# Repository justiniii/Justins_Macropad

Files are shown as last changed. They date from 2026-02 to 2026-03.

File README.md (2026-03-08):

# Justins_Macropad

A 5-key macropad with RGB underglow and OLED display, built around the Seeed XIAO RP2040. Designed for general shortcuts and everyday productivity. Macropad was designed off a sketch of my fingers so its perfectly ergonomic :)

---

## Challenges

This is my first PCB I am planning to manufacture, I used fusion to create the layout using a dxf using a sketch on paper. The keys are positioned to the size and position of my hand. After multiple changes I was eventually happy with the result. Fusion360 was used for 3D modelling with no issues.

---

## Schematic

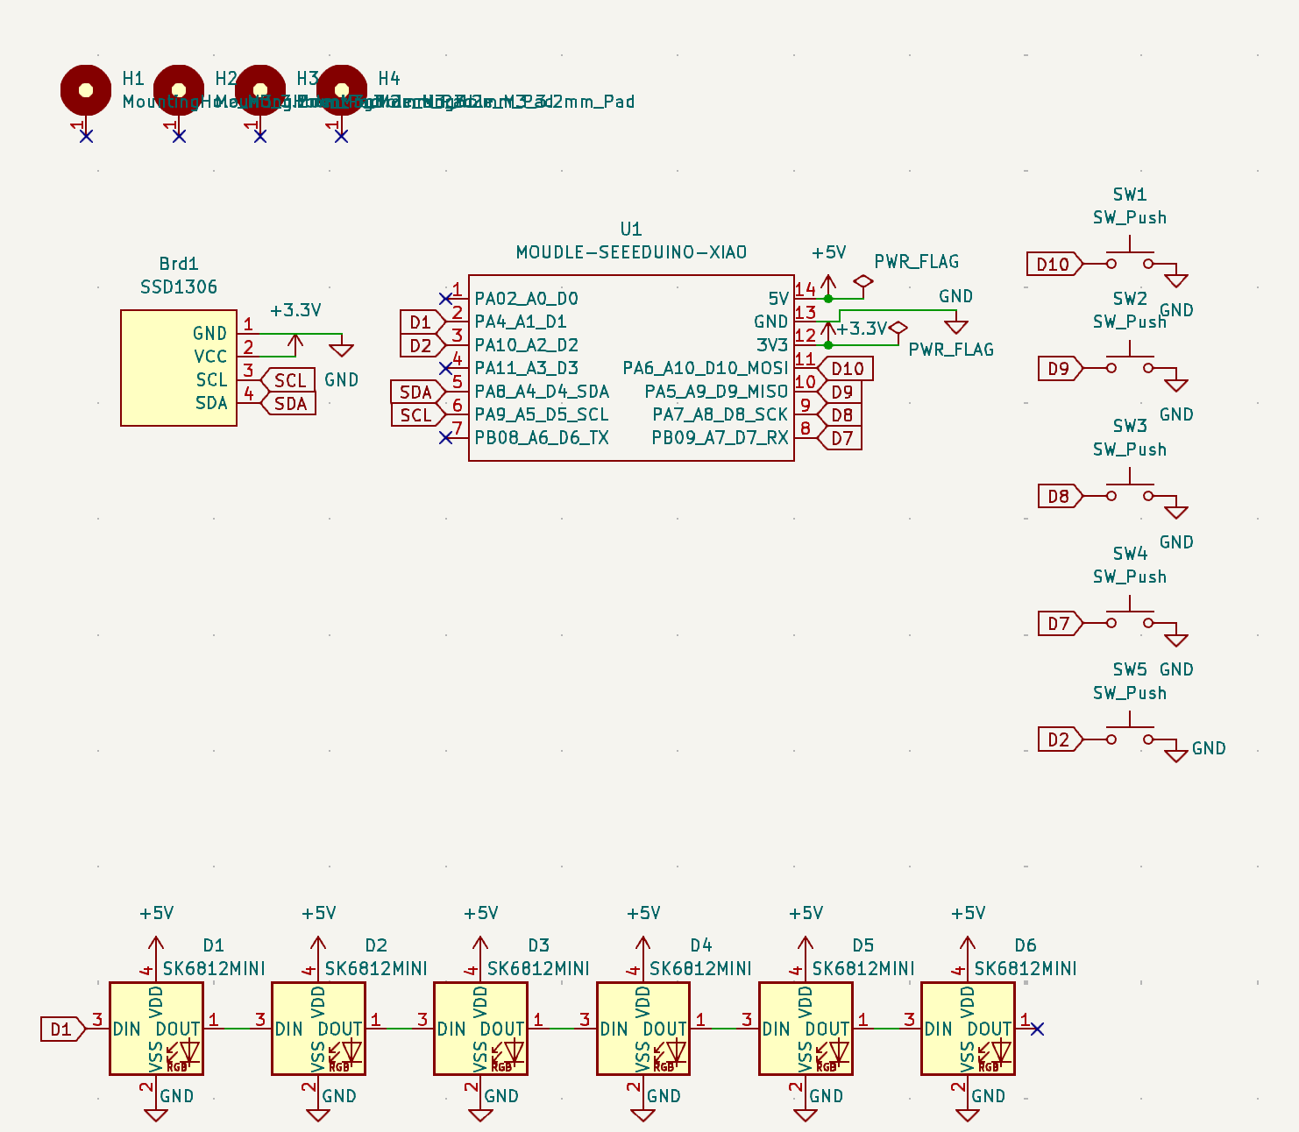
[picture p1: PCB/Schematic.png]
Schematic


---

## PCB

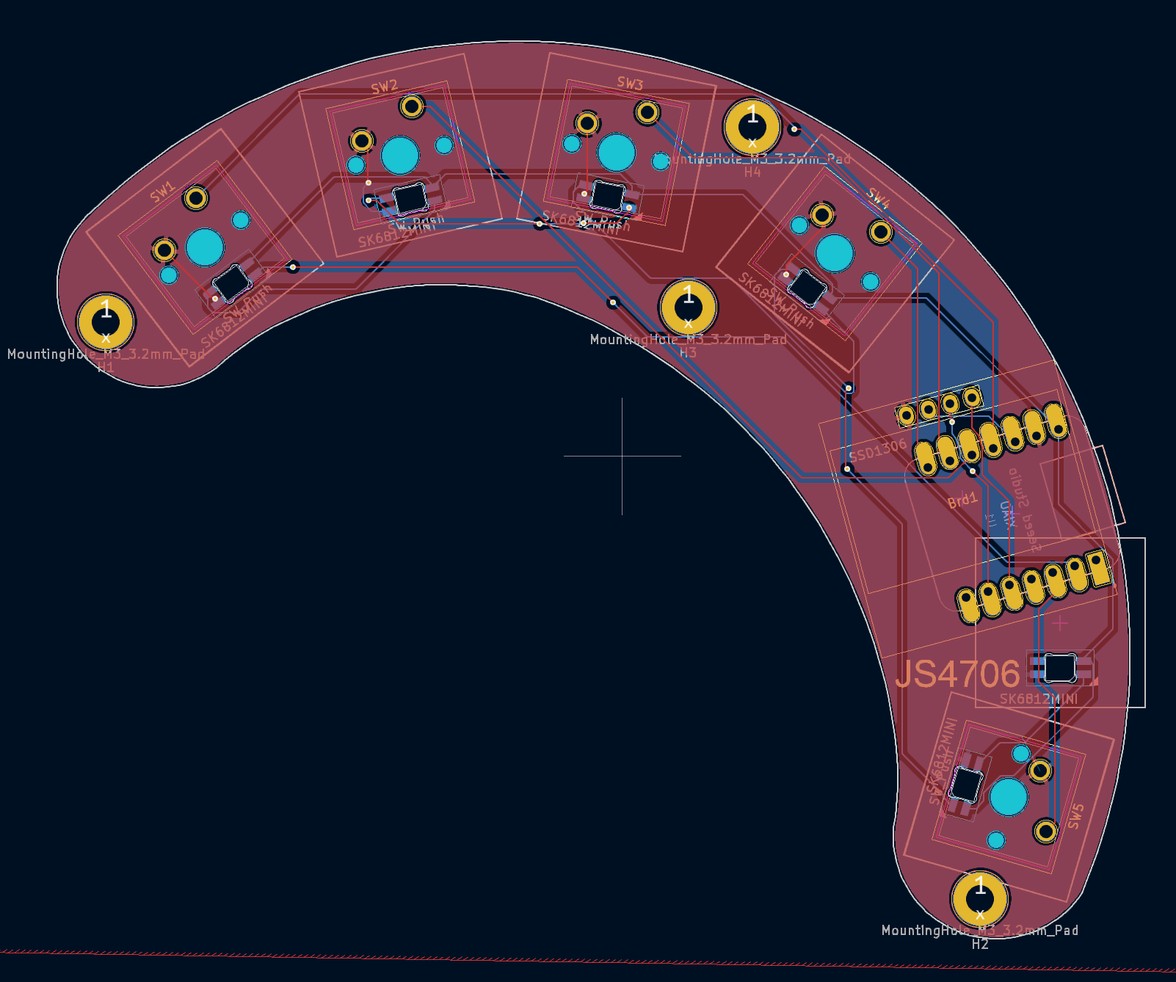
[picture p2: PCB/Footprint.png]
PCB Layout


---

## Case

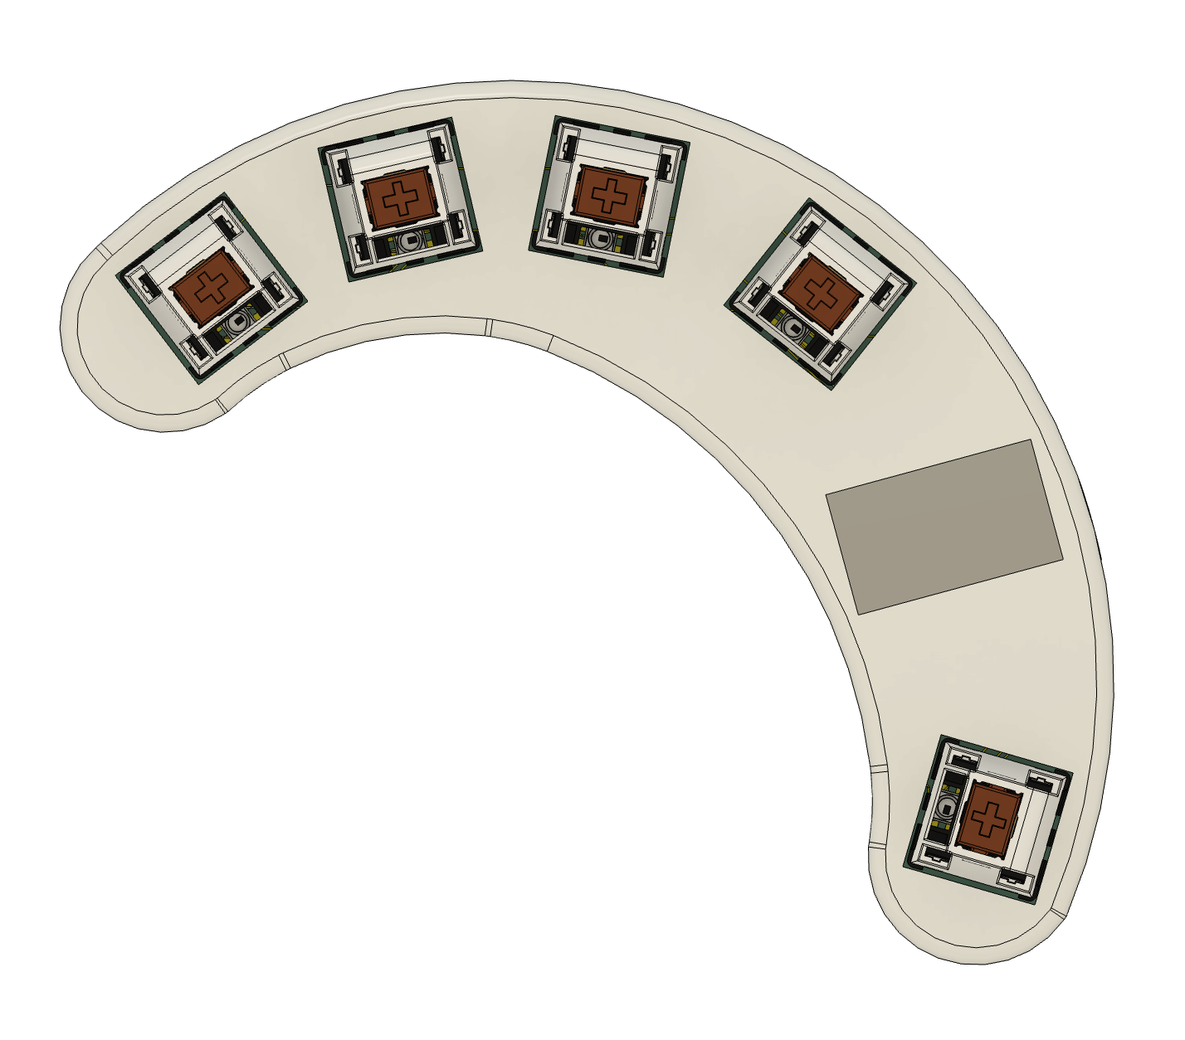
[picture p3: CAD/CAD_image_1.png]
Case1

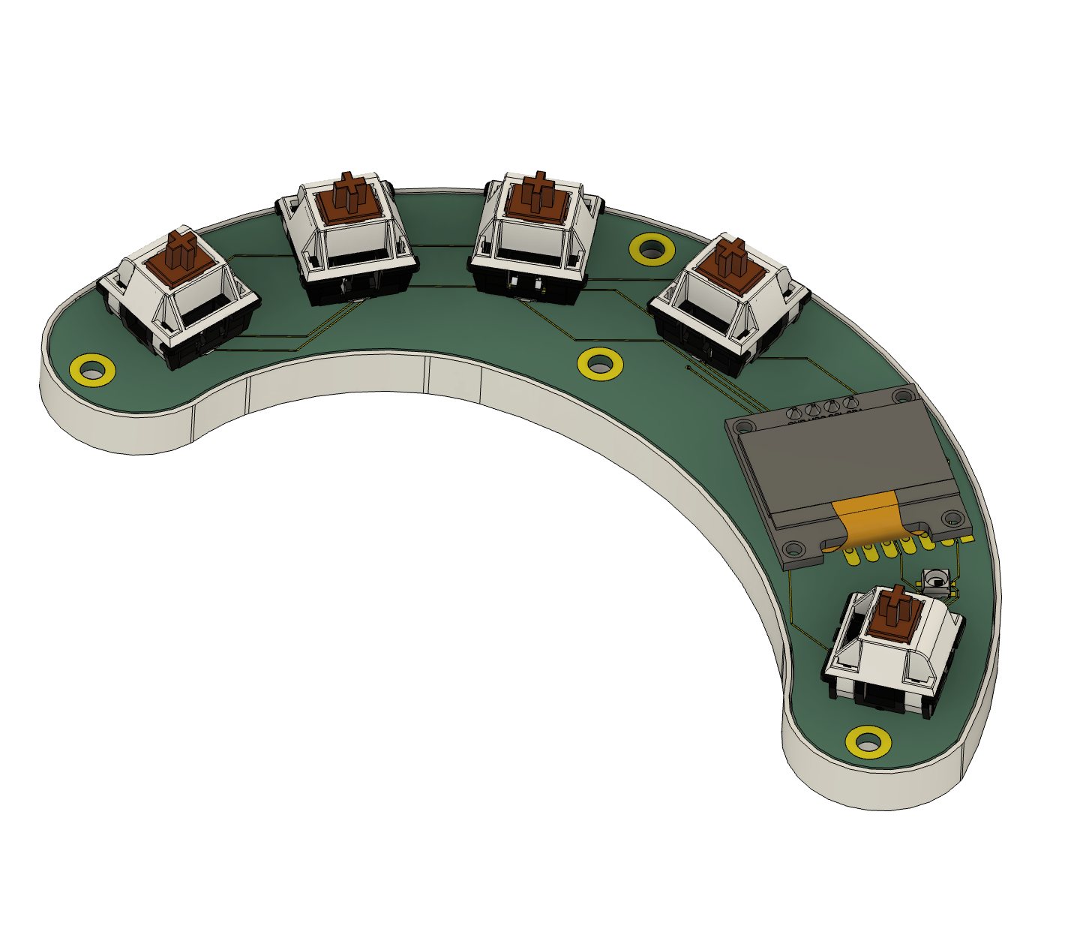
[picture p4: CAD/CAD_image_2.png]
Case2

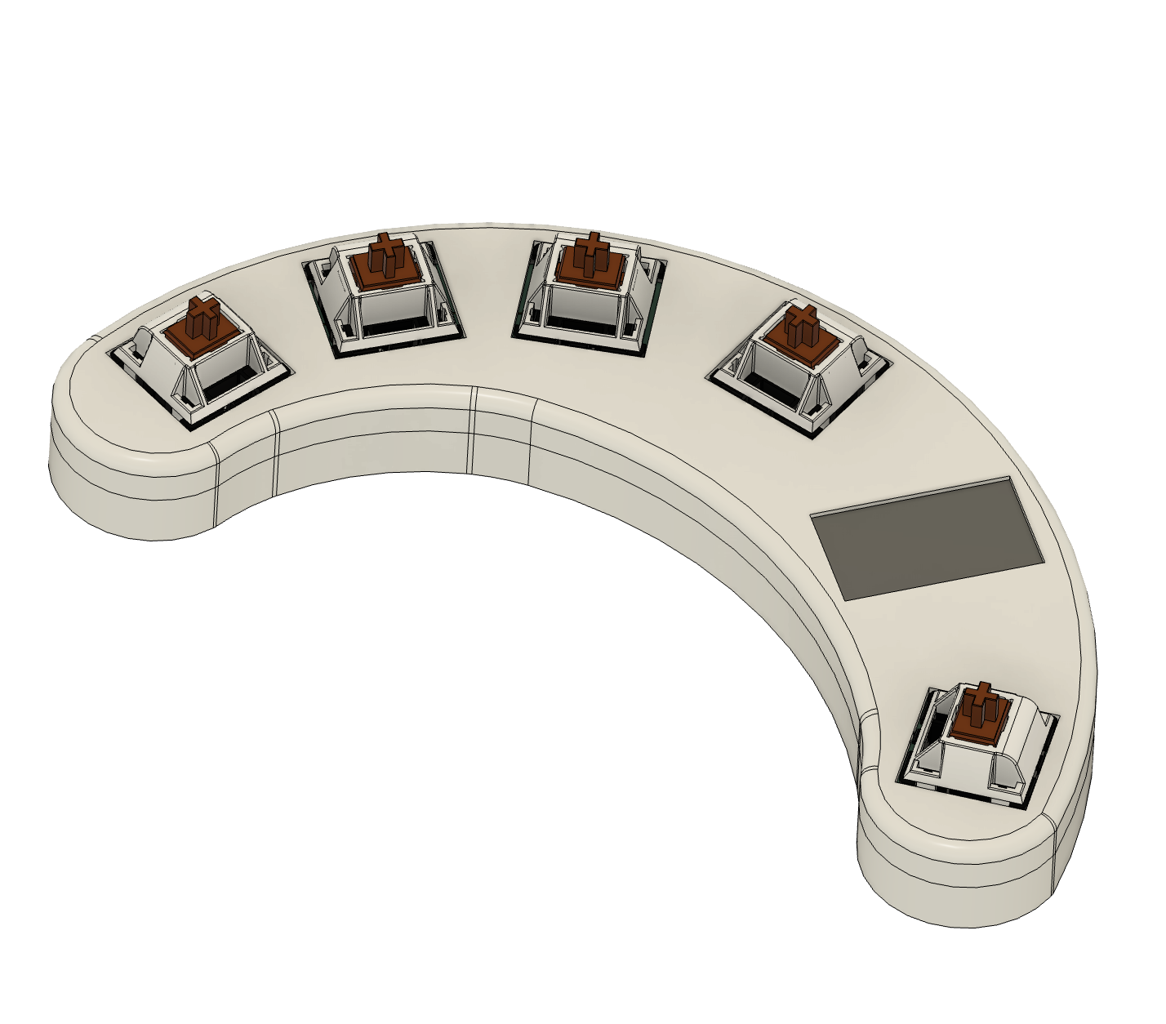
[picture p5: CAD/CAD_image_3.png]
Case3

3D printed two-part case designed to fit the PCB securely, with M3 mounting holes for assembly.

---

## Bill of Materials (BOM)

| Component | Designator | Footprint | Quantity |
|---|---|---|---|
| Seeed XIAO RP2040 | U1 | XIAO-Generic-Hybrid-14P-2.54-21X17.8MM | 1 |
| SK6812MINI RGB LED | D1–D6 | MX_SK6812MINI-E | 6 |
| Cherry MX Push Button Switch | SW1–SW5 | SW_Cherry_MX_1.00u_PCB | 5 |
| SSD1306 128x64 OLED Display | Brd1 | 128x64OLED | 1 |
| M3 Mounting Hole (3.2mm Pad) | H1–H4 | MountingHole_3.2mm_Pad | 4 |
| M3 Screws | — | — | 4 |
| M3 Heat Inserts | — | — | 4 |
| 3D Printed Case | — | — | 1 |

---

## Firmware

This macropad runs [KMK](https://github.com/KMKfw/kmk_firmware) on CircuitPython.

### Setup

1. Flash CircuitPython from [circuitpython.org/board/seeeduino_xiao_rp2040](https://circuitpython.org/board/seeeduino_xiao_rp2040)
2. Copy the `kmk` folder to your `CIRCUITPY` drive
3. Copy `main.py` to the root of your `CIRCUITPY` drive

### Pin Mapping

| Switch | XIAO Pin | GPIO |
|---|---|---|
| SW1 | D10 | GP4 |
| SW2 | D9 | GP3 |
| SW3 | D8 | GP2 |
| SW4 | D7 | GP1 |
| SW5 | D2 | GP28 |
| RGB Data | D1 | GP27 |
| OLED SDA | D4 | GP6 |
| OLED SCL | D5 | GP7 |

---

## License

Open source hardware. Feel free to use, modify, and build on this project!

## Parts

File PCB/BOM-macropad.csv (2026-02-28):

Comment | Designator | Footprint | LCSC | Quantity
SK6812MINI | D6 | MX_SK6812MINI-E |  | 1
SK6812MINI | D5 | MX_SK6812MINI-E |  | 1
SK6812MINI | D4 | MX_SK6812MINI-E |  | 1
SK6812MINI | D3 | MX_SK6812MINI-E |  | 1
SK6812MINI | D2 | MX_SK6812MINI-E |  | 1
SK6812MINI | D1 | MX_SK6812MINI-E |  | 1
MountingHole_M3_3.2mm_Pad | H1 | MountingHole_3.2mm_Pad |  | 1
MountingHole_M3_3.2mm_Pad | H2 | MountingHole_3.2mm_Pad |  | 1
SW_Push | SW3 | SW_Cherry_MX_1.00u_PCB |  | 1
SW_Push | SW5 | SW_Cherry_MX_1.00u_PCB |  | 1
SSD1306 | Brd1 | 128x64OLED |  | 1
MountingHole_M3_3.2mm_Pad | H4 | MountingHole_3.2mm_Pad |  | 1
SW_Push | SW2 | SW_Cherry_MX_1.00u_PCB |  | 1
SW_Push | SW1 | SW_Cherry_MX_1.00u_PCB |  | 1
SW_Push | SW4 | SW_Cherry_MX_1.00u_PCB |  | 1
MountingHole_M3_3.2mm_Pad | H3 | MountingHole_3.2mm_Pad |  | 1
MOUDLE-SEEEDUINO-XIAO | U1 | XIAO-Generic-Hybrid-14P-2.54-21X17.8MM |  | 1

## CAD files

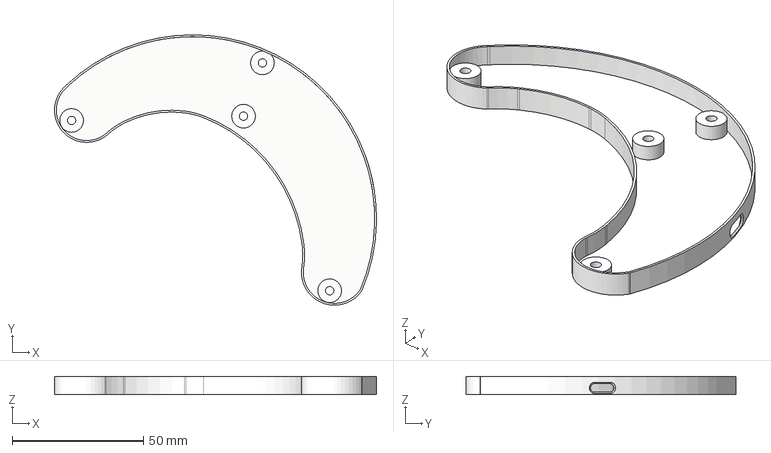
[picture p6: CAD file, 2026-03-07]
CAD/BOTTOM.step
122.6 x 102.9 x 7.00 mm

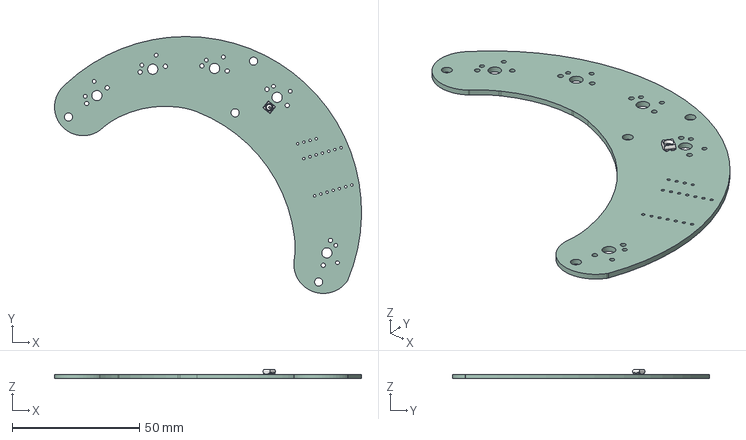
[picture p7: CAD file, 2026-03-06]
PCB/macropad.step
120.6 x 100.9 x 3.65 mm
WS2812B-MINI v1
macropad_PCB

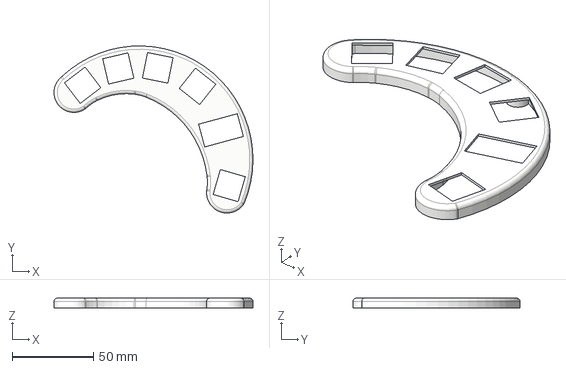
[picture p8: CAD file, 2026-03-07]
CAD/TOP.step
122.6 x 102.9 x 6.00 mm

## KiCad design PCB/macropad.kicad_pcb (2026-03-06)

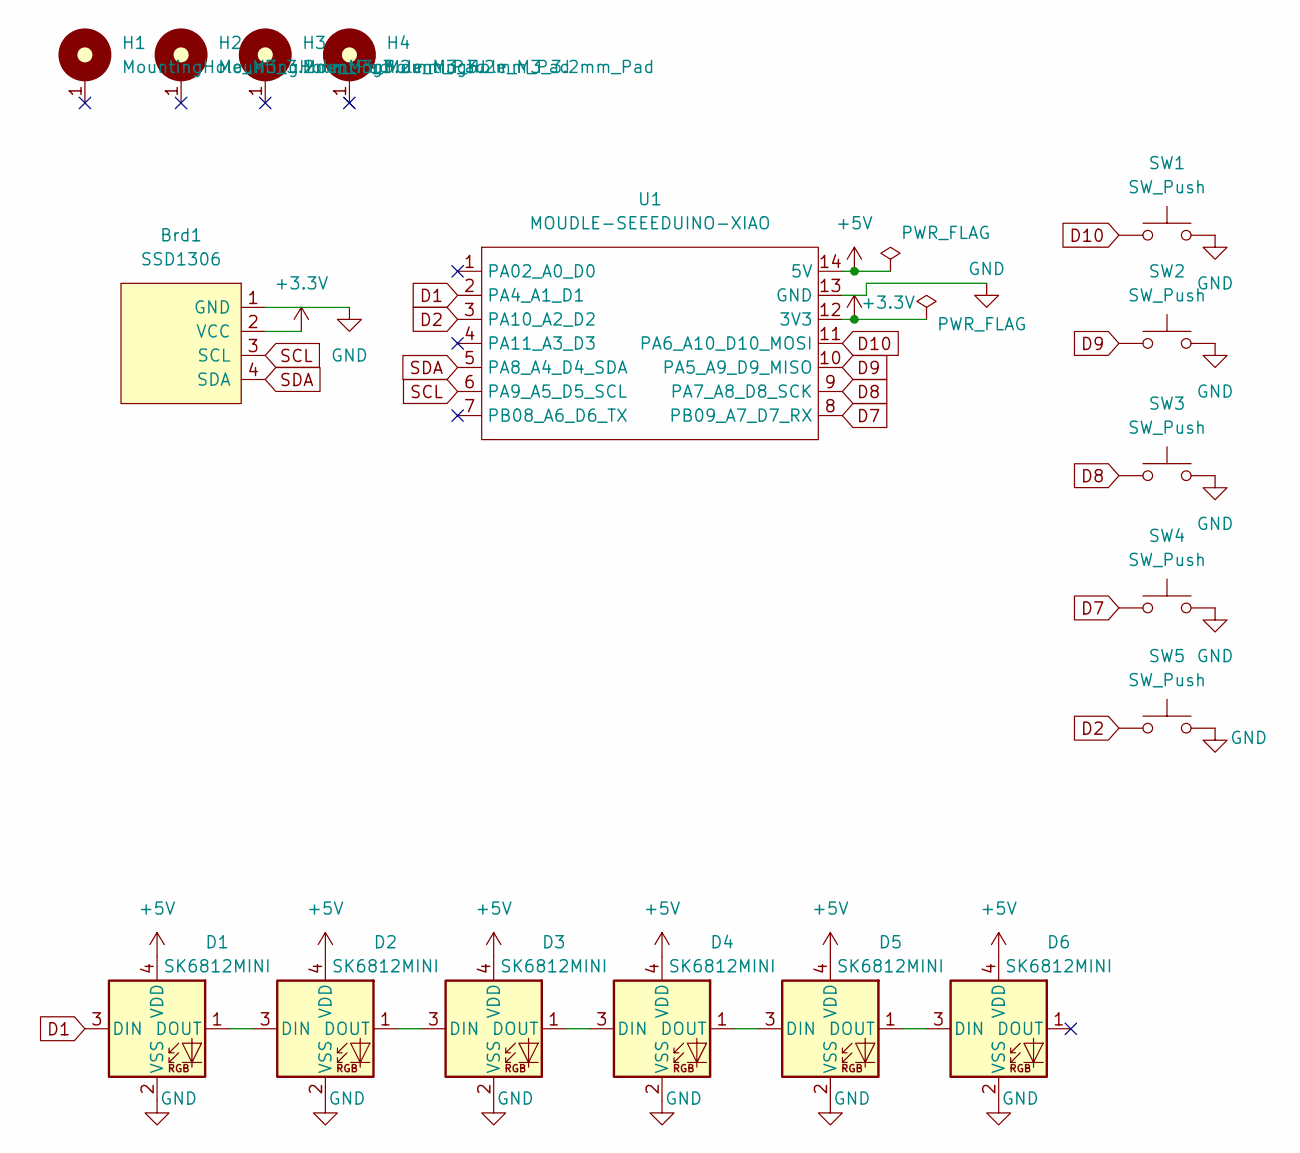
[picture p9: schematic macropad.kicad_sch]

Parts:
Brd1: SSD1306; 128x64OLED
D1, D2, D3, D4, D5, D6: SK6812MINI; MX_SK6812MINI-E
H1, H2, H3, H4: MountingHole_M3_3.2mm_Pad; MountingHole_3.2mm_Pad
SW1, SW2, SW3, SW4, SW5: SW_Push; SW_Cherry_MX_1.00u_PCB
U1: MOUDLE-SEEEDUINO-XIAO; XIAO-Generic-Hybrid-14P-2.54-21X17.8MM

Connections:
+3.3V: Brd1.2 (VCC), U1.12 (3V3)
+5V: D1.4 (VDD), D2.4 (VDD), D3.4 (VDD), D4.4 (VDD), D5.4 (VDD), D6.4 (VDD), U1.14 (5V)
D1: D1.3 (DIN), U1.2 (PA4_A1_D1)
D2: SW5.1, U1.3 (PA10_A2_D2)
D7: SW4.1, U1.8 (PB09_A7_D7_RX)
D8: SW3.1, U1.9 (PA7_A8_D8_SCK)
D9: SW2.1, U1.10 (PA5_A9_D9_MISO)
D10: SW1.1, U1.11 (PA6_A10_D10_MOSI)
GND: Brd1.1 (GND), D1.2 (VSS), D2.2 (VSS), D3.2 (VSS), D4.2 (VSS), D5.2 (VSS), D6.2 (VSS), SW1.2, SW2.2, SW3.2, SW4.2, SW5.2, U1.13 (GND)
unnamed: D1.1 (DOUT), D2.3 (DIN)
unnamed: D2.1 (DOUT), D3.3 (DIN)
unnamed: D3.1 (DOUT), D4.3 (DIN)
unnamed: D4.1 (DOUT), D5.3 (DIN)
unnamed: D5.1 (DOUT), D6.3 (DIN)
SCL: Brd1.3 (SCL), U1.6 (PA9_A5_D5_SCL)
SDA: Brd1.4 (SDA), U1.5 (PA8_A4_D4_SDA)

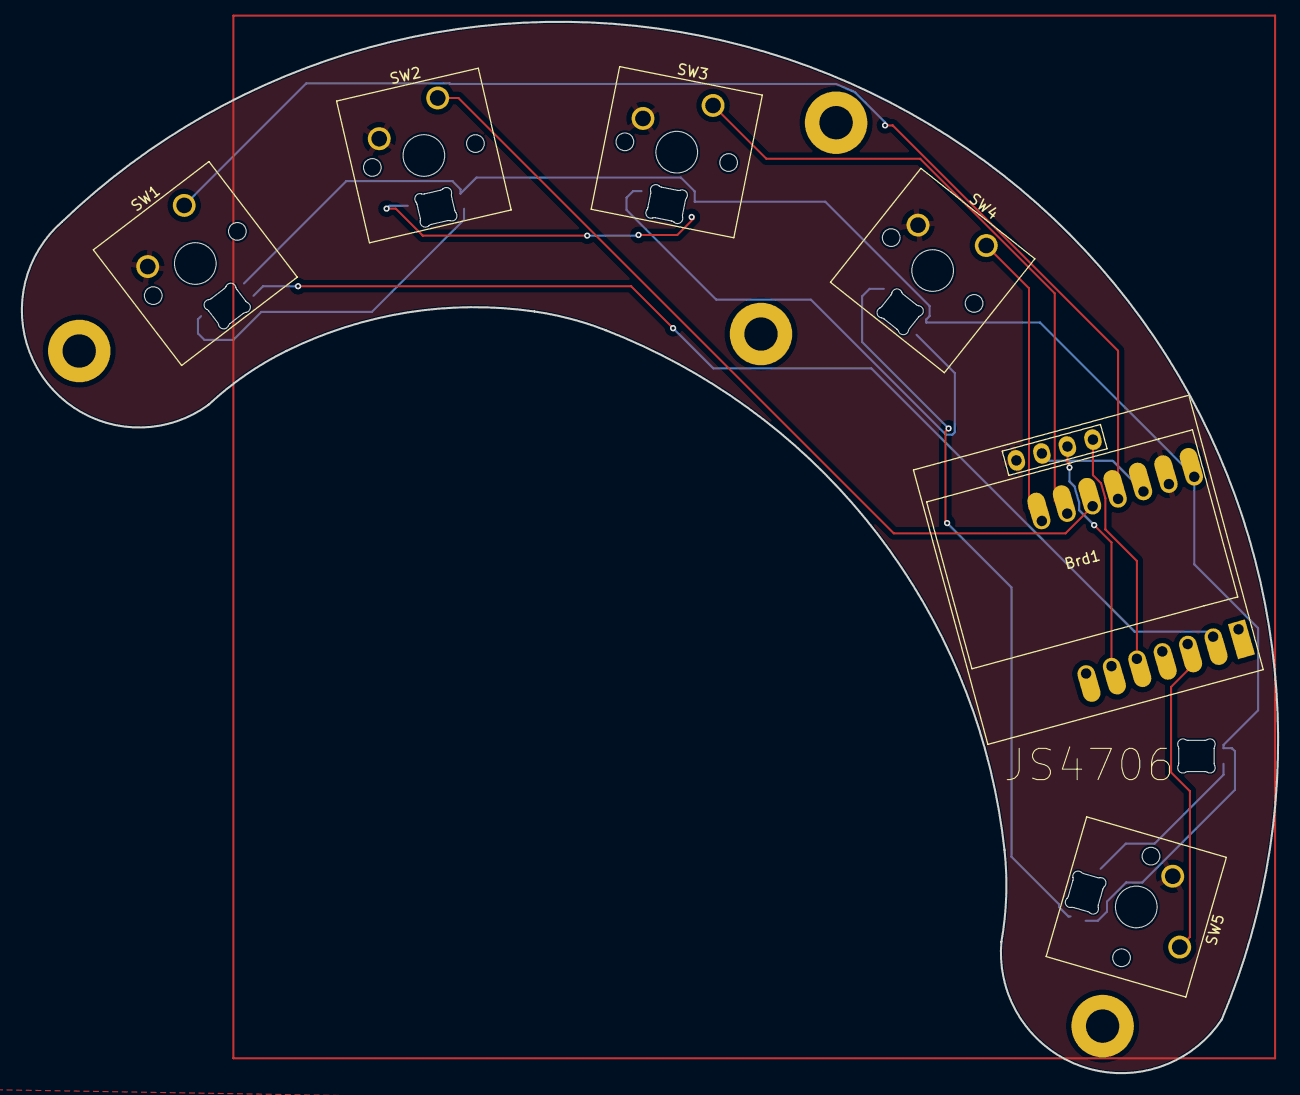
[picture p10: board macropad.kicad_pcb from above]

Board: 2 copper layers, 120.6 x 100.9 mm, 17 parts (1 on the bottom side), 16 nets.

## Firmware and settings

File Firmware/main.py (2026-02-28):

import board
from kmk.kmk_keyboard import KMKKeyboard
from kmk.keys import KC
from kmk.scanners.keypad import KeysScanner
from kmk.modules.macros import Macros, Macro, Press, Release, Tap
from kmk.modules.layers import Layers
from kmk.extensions.RGB import RGB
from kmk.extensions.oled import Oled, OledData, OledDisplayMode

keyboard = KMKKeyboard()

# ── Direct pin wiring (each switch has its own GPIO) ──────────────────────────
# SW1=D10=GP4, SW2=D9=GP3, SW3=D8=GP2, SW4=D7=GP1, SW5=D2=GP28
keyboard.modules.append(Macros())
keyboard.modules.append(Layers())

keyboard.matrix = KeysScanner(
    pins=[
        board.GP4,   # SW1
        board.GP3,   # SW2
        board.GP2,   # SW3
        board.GP1,   # SW4
        board.GP28,  # SW5
    ]
)

# ── RGB (6x SK6812MINI on GP27) ───────────────────────────────────────────────
rgb = RGB(
    pixel_pin=board.GP27,
    num_pixels=6,
    val_limit=150,       # cap brightness (SK6812MINI get hot at full power)
    hue_default=0,
    sat_default=255,
    val_default=80,
)
keyboard.extensions.append(rgb)

# ── OLED (SSD1306 on SDA=GP6, SCL=GP7) ───────────────────────────────────────
oled = Oled(
    OledData(
        corner_one={0: OledDisplayMode.TXT, 1: ["MACROPAD"]},
        corner_two={0: OledDisplayMode.TXT, 1: ["Layer:"]},
        corner_three={0: OledDisplayMode.TXT, 1: ["SW1-SW5"]},
        corner_four={0: OledDisplayMode.TXT, 1: ["KMK Ready"]},
    ),
    toDisplay=OledDisplayMode.TXT,
    flip=False,
)
keyboard.extensions.append(oled)

# ── Layers ────────────────────────────────────────────────────────────────────
# Layer 0 = Base
# Layer 1 = Fn (hold SW5)

SW5_FN = KC.MO(1)   # hold SW5 to access Fn layer

keyboard.keymap = [
    # Layer 0 — Base
    # Change KC.A / KC.B etc. to whatever you want!
    [
        KC.A,     # SW1
        KC.B,     # SW2
        KC.C,     # SW3
        KC.D,     # SW4
        SW5_FN,   # SW5 — hold for Fn
    ],
    # Layer 1 — Fn (hold SW5)
    [
        KC.RGB_TOG,  # SW1 — toggle RGB on/off
        KC.RGB_MOD,  # SW2 — cycle RGB animation
        KC.RGB_HUI,  # SW3 — hue up
        KC.RGB_SAI,  # SW4 — saturation up
        KC.TRNS,     # SW5 — (held)
    ],
]

if __name__ == "__main__":
    keyboard.go()

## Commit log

2026-02-28 initial upload
    [BOM-macropad.csv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]
2026-03-06 All required files uploaded
    [BOM-macropad.csv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]
2026-03-07 added specific files
    [BOTTOM.step, TOP.step]
2026-03-08 moved files
    [BOM-macropad.csv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]
